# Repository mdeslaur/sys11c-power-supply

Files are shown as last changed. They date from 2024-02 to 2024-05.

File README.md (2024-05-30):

# Williams System 11B/11C Power Supply

This is a replacement power supply for use in Williams System 11B/11C
pinball machines. The original part number is D-12246.

When being used with low-voltage LED displays, all parts in the 100v
sections can be left unpopulated.

It is in KiCad 7 format.

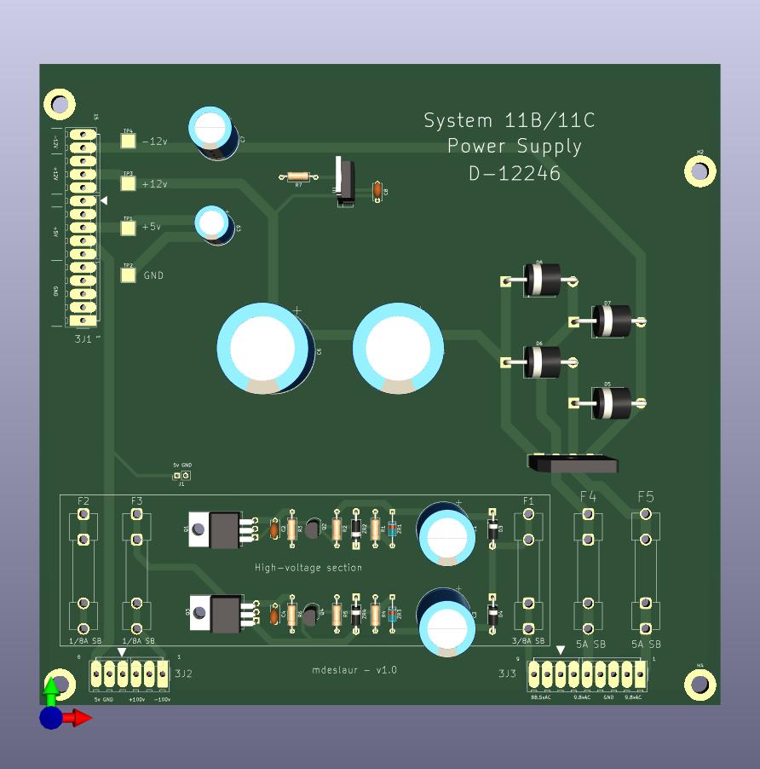
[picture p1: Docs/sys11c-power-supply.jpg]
Render of PCB


See Docs/parts-list.txt for a list of parts. Make sure the regulator is
installed the right way. The square pad is pin 1, and the pin numbers are
printed on it. Also, you can use either the bridge rectifier, or individual
diodes, don't install both.

The gerbers for JLCPCB are in the zip file in the gerbers directory.

This has been tested in both a Williams Taxi and a Williams Diner with
low-voltage LED displays. The high-voltage section has not been tested, so
please let me know if it works.

Change history:  
1.0 - Initial version  

To Do:  
- Change silkscreen for regulator to better indicate orientation  
- Make sure there's enough room for the Q1 and Q3 heatsinks

Marc Deslauriers  
2024-01-31

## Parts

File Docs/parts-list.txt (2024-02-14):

Parts List:

Main section:

U1 - PTR08060WVD Texas Instruments Switching Regulator
D1 - 6A Bridge GBU6B
D5-D8 - 6A diodes GI751 (optional, instead of D1)
C5,C6 - 10,000uF 20v Electrolytic Capacitor
C7 - 1000uF 25v Electrolytic Capacitor
C8 - 22uF 20v Ceramic Capacitor
C9 - 2200uF 16v Electrolytic Capacitor
R7 - 267 ohm, 1/4W, 1% resistor
F4,F5 - Fuse clips, 5A SB fuse
3J1 - Molex 3.96MM 15-pin header
3J2 - Molex 3.96MM 6-pin header
3J3 - Molex 3.96MM 9-pin header

Optional high-voltage section:
(Not used when low-voltage LED displays are used)

Q1 - MJE15030 transistor
Q2 - 2N5401 transistor
Q3 - MJE15031 transistor
Q4 - 2N5551 transistor
C1,C3 - 150uF 160v Electrolytic Capacitor
C2,C4 - 0.1uF 500v Ceramic capacitor
R1,R4 - 39K ohm 1W resistor
R2,R5 - 680 ohm 1/2W resistor
R3,R6 - 300K ohm 1/2W resistor
ZR1,ZR3 - 1N5990 Zener diode
ZR2,ZR4 - 1N4764 Zener diode
F1 - Fuse clips, 3/8A SB fuse
F2,F3 - Fuse clips, 1/8A SB fuse
Two TO-220 heatsinks for Q1 and Q3

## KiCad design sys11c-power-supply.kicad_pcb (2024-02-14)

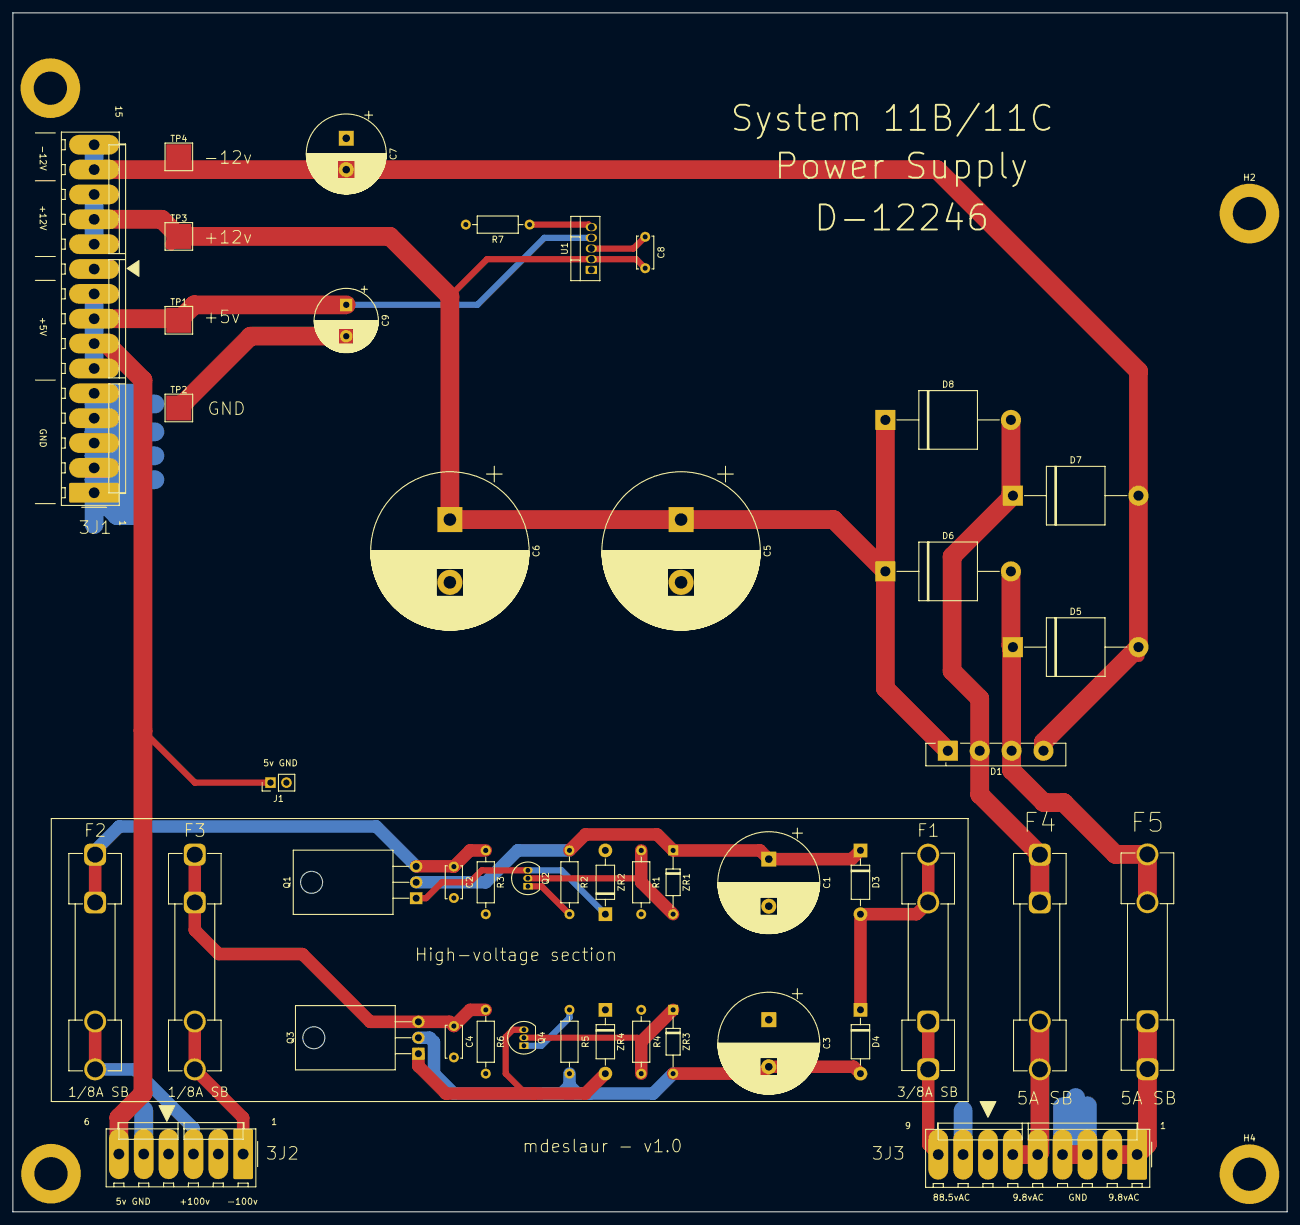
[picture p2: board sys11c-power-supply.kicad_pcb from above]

Board: 2 copper layers, 203.0 x 191.0 mm, 49 parts (0 on the bottom side), 23 nets.

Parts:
3J1: Conn_01x15; Molex_KK-396_A-41791-0015_1x15_P3.96mm_Vertical
3J2: Conn_01x06; Molex_KK-396_A-41791-0006_1x06_P3.96mm_Vertical
3J3: Conn_01x09; Molex_KK-396_A-41791-0009_1x09_P3.96mm_Vertical
C1, C3: 150uF 160v; CP_Radial_D16.0mm_P7.50mm
C2, C4: 0.1uF; C_Disc_D5.0mm_W2.5mm_P5.00mm
C5, C6: 10,000uF; CP_Radial_D25.0mm_P10.00mm_SnapIn
C7: 1000uF; CP_Radial_D12.5mm_P5.00mm
C8: 22uF Cer; C_Disc_D5.0mm_W2.5mm_P5.00mm
C9: 2200uF 16V; CP_Radial_D10.0mm_P5.00mm
D1: GBU6B; Diode_Bridge_Vishay_GBU
D3, D4: 1N4004; D_DO-41_SOD81_P10.16mm_Horizontal
D5, D6, D7, D8: D_Filled; D_P600_R-6_P20.00mm_Horizontal
F1: 3/8A SB; Fuseholder_Clip-6.3x32mm_Littelfuse_102_Inline_P34.21x7.62m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
F2, F3: 1/8A SB; Fuseholder_Clip-6.3x32mm_Littelfuse_102_Inline_P34.21x7.62m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
F4, F5: 5A SB; Fuseholder_Clip-6.3x32mm_Littelfuse_102_Inline_P34.21x7.62m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
H1, H2, H3, H4: MountingHole_Pad; MountingHole_5.3mm_M5_ISO7380_Pad
J1: Optional Voltmeter; PinHeader_1x02_P2.54mm_Vertical
Q1: MJE15030; TO-220-3_Horizontal_TabDown
Q2: 2N5401; TO-92_Inline
Q3: MJE15031; TO-220-3_Horizontal_TabDown
Q4: 2N5551; TO-92_Inline
R1, R4: 39K 1W; R_Axial_DIN0207_L6.3mm_D2.5mm_P10.16mm_Horizontal
R2, R5: 680 1/2W; R_Axial_DIN0207_L6.3mm_D2.5mm_P10.16mm_Horizontal
R3, R6: 330K 1/2W; R_Axial_DIN0207_L6.3mm_D2.5mm_P10.16mm_Horizontal
R7: 267 1%; R_Axial_DIN0207_L6.3mm_D2.5mm_P10.16mm_Horizontal
TP1: +5v TP; TestPoint_Pad_4.0x4.0mm
TP2: GND TP; TestPoint_Pad_4.0x4.0mm
TP3: +12v TP; TestPoint_Pad_4.0x4.0mm
TP4: -12v TP; TestPoint_Pad_4.0x4.0mm
U1: PTR08060WVD; TO-220-5_Vertical
ZR1, ZR3: 1N5990; D_DO-35_SOD27_P10.16mm_Horizontal
ZR2, ZR4: 1N4764; D_DO-41_SOD81_P10.16mm_Horizontal

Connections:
/+5v: 3J1.6, 3J1.7, 3J1.8, 3J1.9, 3J2.6, C9.1, J1.1, TP1.1, U1.4 (VO)
/+12v Unreg: 3J1.11, 3J1.12, 3J1.13, C5.1, C6.1, C8.1, D1.1 (+), D6.1 (K), D8.1 (K), TP3.1, U1.2 (VI)
/+100v: 3J2.3, F2.2
/-12v Unreg: 3J1.14, 3J1.15, C7.2, D1.4 (-), D5.2 (A), D7.2 (A), TP4.1
/-100v: 3J2.1, F3.2
GND: 3J1.1, 3J1.2, 3J1.3, 3J1.4, 3J1.5, 3J2.5, 3J3.3, 3J3.4, 3J3.8, C1.2, C2.2, C3.1, C4.2, C5.2, C6.2, C7.1, C8.2, C9.2, H1.1, H2.1, H3.1, H4.1, J1.2, R1.2, R3.2, R4.2, R6.2, R7.2, TP2.1, U1.3 (GND), ZR2.2 (A), ZR4.1 (K)
unnamed: 3J3.1, 3J3.2, F5.1
unnamed: 3J3.5, 3J3.6, F4.2
unnamed: 3J3.9, F1.1
unnamed: D3.2 (A), D4.1 (K), F1.2
unnamed: C1.1, D3.1 (K), Q1.2 (C), R2.1, ZR1.1 (K)
unnamed: C3.2, D4.2 (A), Q3.2 (C), R5.1, ZR3.2 (A)
unnamed: D1.3, D5.1 (K), D6.2 (A), F5.2
unnamed: D1.2, D7.1 (K), D8.2 (A), F4.1
unnamed: Q1.1 (B), Q2.3 (C), ZR2.1 (K)
unnamed: C2.1, F2.1, Q1.3 (E), R3.1
unnamed: Q2.2 (B), R1.1, ZR1.2 (A)
unnamed: Q2.1 (E), R2.2
unnamed: Q3.1 (B), Q4.3 (C), ZR4.2 (A)
unnamed: C4.1, F3.1, Q3.3 (E), R6.1
unnamed: Q4.2 (B), R4.1, ZR3.1 (K)
unnamed: Q4.1 (E), R5.2
unnamed: R7.1, U1.5 (VOADJUST)

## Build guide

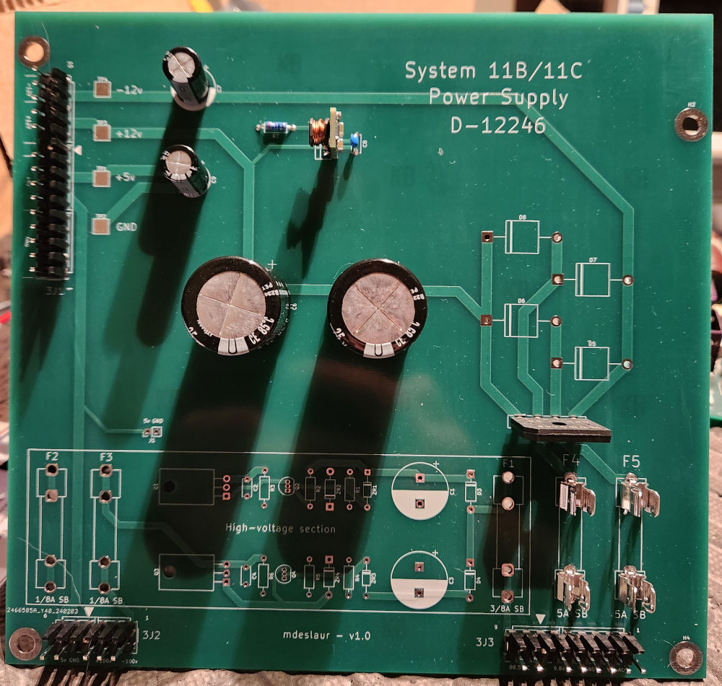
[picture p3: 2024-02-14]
Docs/assembled-pcb.jpg

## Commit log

2024-02-14 clarify use of bridge or diodes
2024-02-14 add heatsinks to parts list and add a todo to check space for them
